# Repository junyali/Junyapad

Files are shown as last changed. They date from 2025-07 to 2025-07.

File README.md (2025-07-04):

# Junyapad

A custom 6-key macropad featuring per-key RGB LEDs (with some extras :p) a 128x32 0.91" OLD screen, a rotary encoder switch and a cool semi-open case design!

PCB designed in KiCAD, case built in OnShape, and firmware built using QMK. Pretty proud of this as it's fully independent (no assistance from friends needed or Q's asked :DD)

## Preview

| Description | Image |
|---|---|
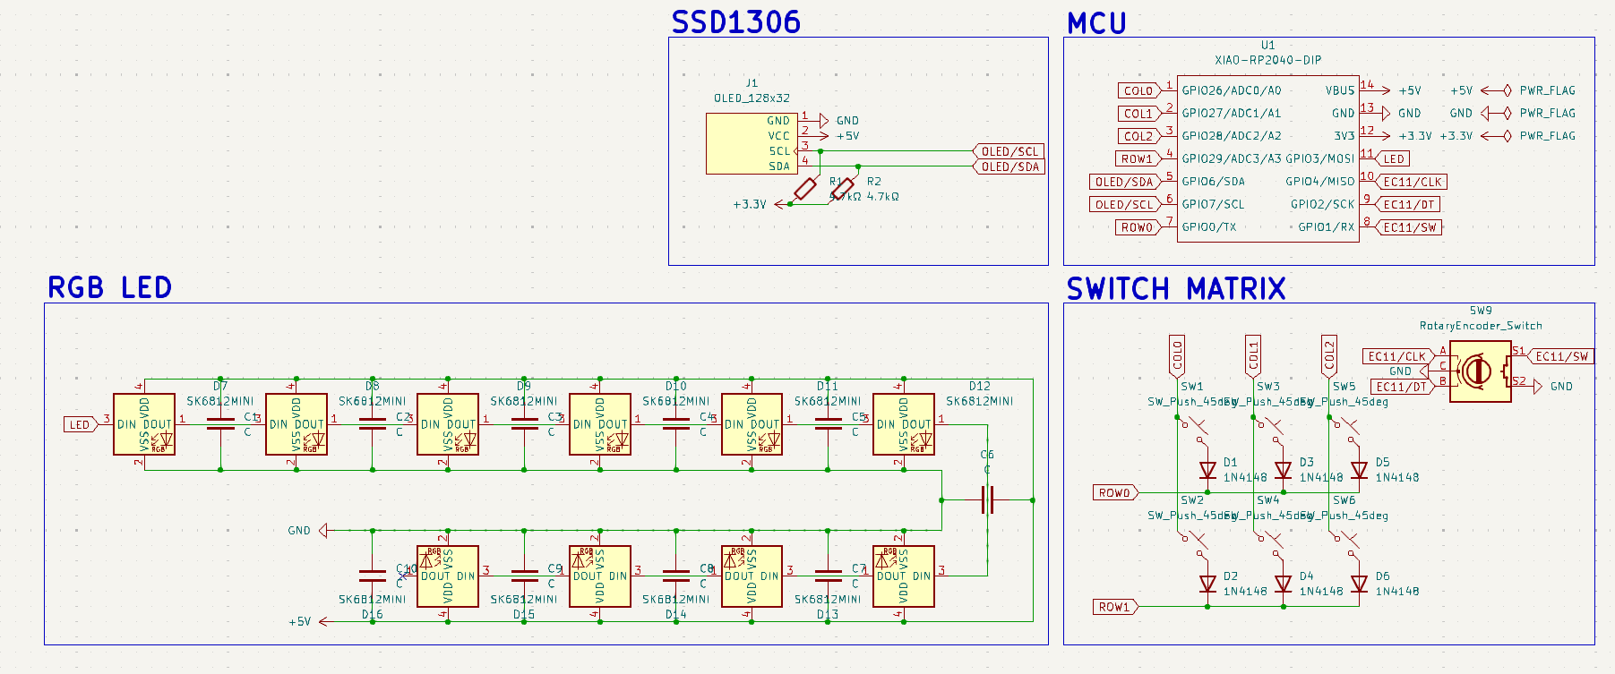
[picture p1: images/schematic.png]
| Schematic |  |
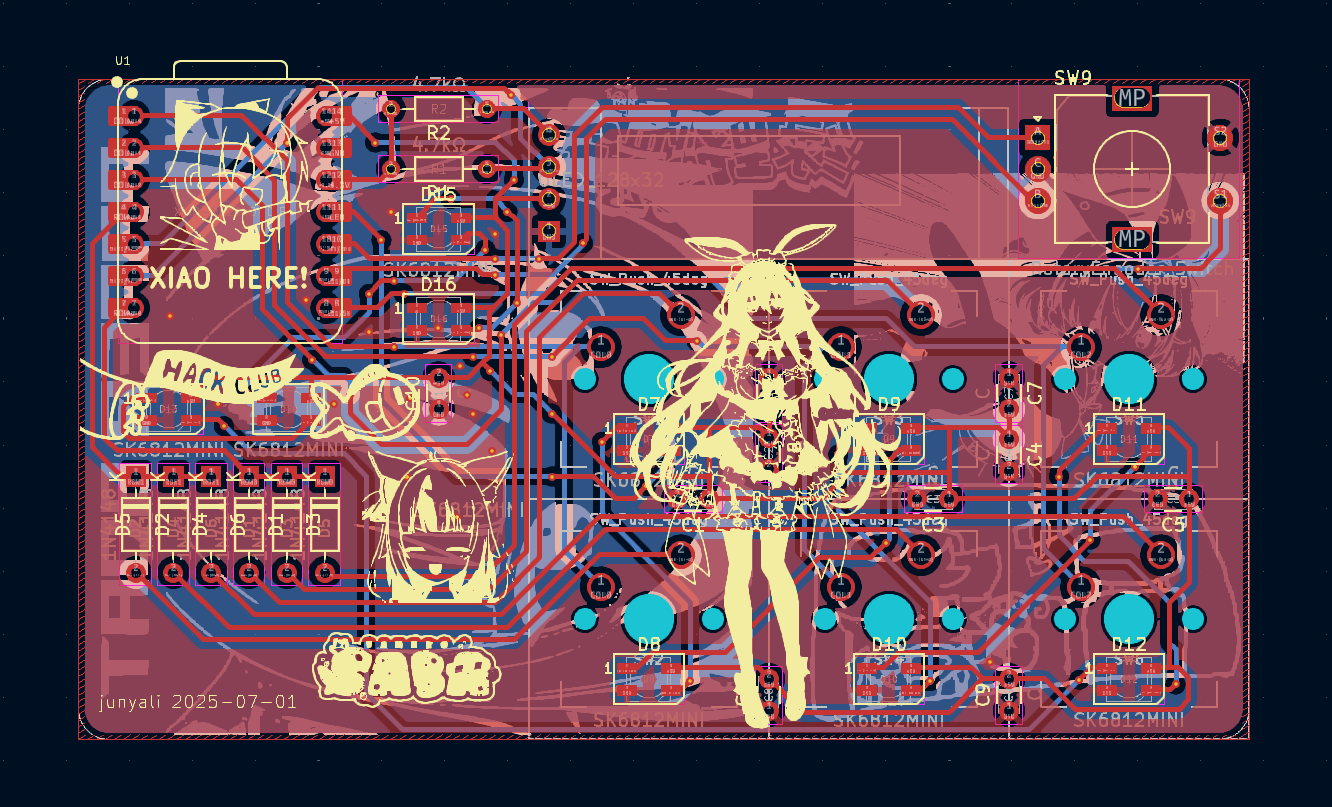
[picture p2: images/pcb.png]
| PCB |  |
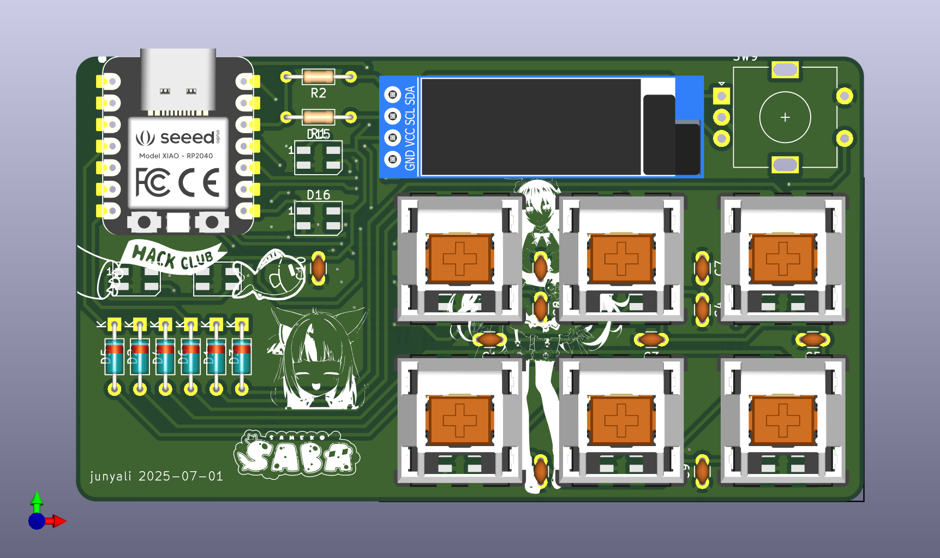
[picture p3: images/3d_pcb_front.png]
| PCB Render Front |  |
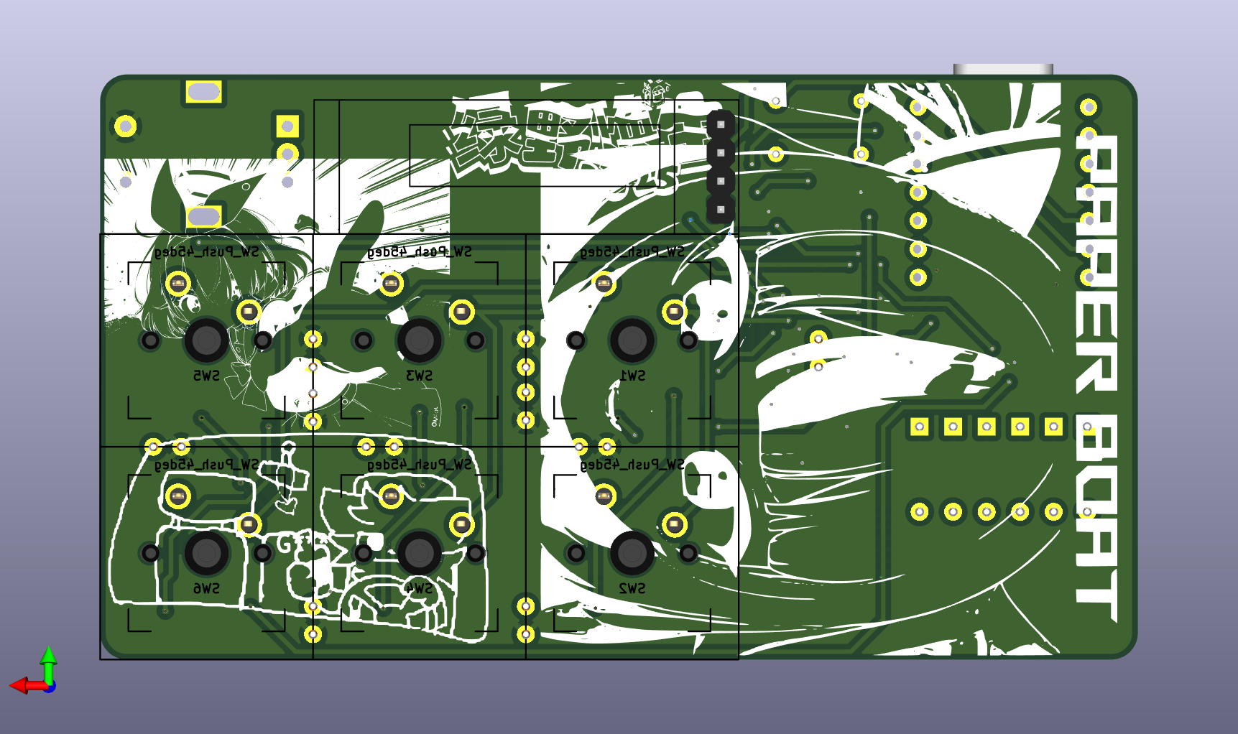
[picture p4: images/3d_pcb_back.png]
| PCB Render Back  |   |
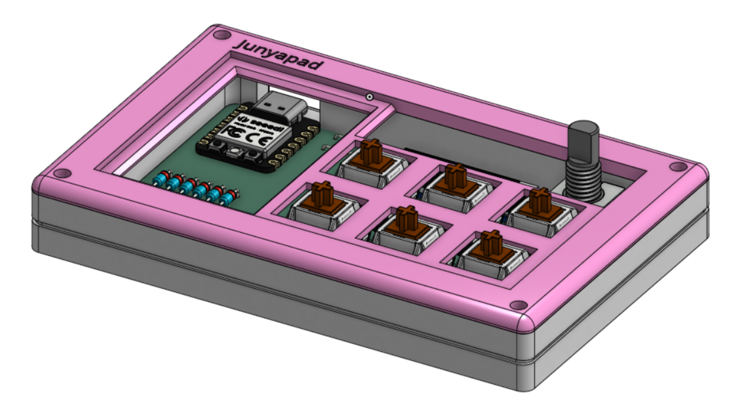
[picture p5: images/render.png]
| Case Render |  |

## BOM

| Component | Footprint | Qty | Unit Price (£) | Total Price (£) | Link |
|---|---|-----|---|---|---|
| SEEED XIAO RP2040 | XIAO-RP2040-DIP | 1 | 3.99 | 3.99 | https://www.aliexpress.com/item/1005004459618789.html |
| Cherry MX switches | N/A | 6 | 0.21 | 1.26 | https://www.aliexpress.com/item/1005006255961111.html |
| Generic Keycaps | N/A | 6 | 0.75 | 0.75 | https://www.aliexpress.com/item/1005005386897424.html |
| 1N4148 Diodes | D_DO-35_SOD27_P7.62mm_Horizontal | 6 | 0.02 | 0.12 | https://www.aliexpress.com/item/1005006245109375.html |
| SK6812 MINI LEDs | LED_SK6812MINI_PLCC4_3.5x3.5mm_P1.75mm | 10  | 0.08 | 0.80 | https://www.aliexpress.com/item/1005001971988539.html |
| 128x32 0.91" OLED Display | OLED_128x32 | 1 | 0.74 | 0.74 | https://www.aliexpress.com/item/1005008640132638.html |
| EC11 Rotary Encoder Switch | RotaryEncoder_Alps_EC11E-Switch_Vertical_H20mm | 1 | 0.74 | 0.74 | https://www.aliexpress.com/item/1005004907970664.html |
| 4.7kΩ Resistors | R_Axial_DIN0204_L3.6mm_D1.6mm_P7.62mm_Horizontal | 2 | 0.05 | 0.10 | https://www.aliexpress.com/item/1005006427040577.html |
| 0.1uF Disc Capacitors | C_Disc_D3.0mm_W1.6mm_P2.50mm | 10  | 0.01 | 0.10 | https://www.aliexpress.com/item/32973259342.html |
| M3x16mm screws | N/A | 4 | 0.04 | 0.16 | https://www.aliexpress.com/item/32844540184.html |
| M3 hex nuts | N/A | 4 | 0.03 | 0.12 | https://www.aliexpress.com/item/1005007593861199.html |
| PCB Fabricated (JLCPCB, incl shipping) | N/A | 5 | 0.94 | 4.70 | https://jlcpcb.com |
| 3D Printed Case (#printing-legion) | N/A | 1 | 0.00 | 0.00 | https://printlegion.hackclub.com |

Total Price: **£13.58** (*approx US$18.54*)

*Prices are a bit wonky since most products must be bought in bulk - this is an optimistic BOM*

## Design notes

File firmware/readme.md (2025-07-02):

# junyapad

junyapad

*A short description of the keyboard/project*

* Keyboard Maintainer: [Junya](https://github.com/junyali)
* Hardware Supported: *The PCBs, controllers supported*
* Hardware Availability: *Links to where you can find this hardware*

Make example for this keyboard (after setting up your build environment):

    make junyapad:default

Flashing example for this keyboard:

    make junyapad:default:flash

See the [build environment setup](https://docs.qmk.fm/#/getting_started_build_tools) and the [make instructions](https://docs.qmk.fm/#/getting_started_make_guide) for more information. Brand new to QMK? Start with our [Complete Newbs Guide](https://docs.qmk.fm/#/newbs).

## Bootloader

Enter the bootloader in 3 ways:

* **Bootmagic reset**: Hold down the key at (0,0) in the matrix (usually the top left key or Escape) and plug in the keyboard
* **Physical reset button**: Briefly press the button on the back of the PCB - some may have pads you must short instead
* **Keycode in layout**: Press the key mapped to `QK_BOOT` if it is available

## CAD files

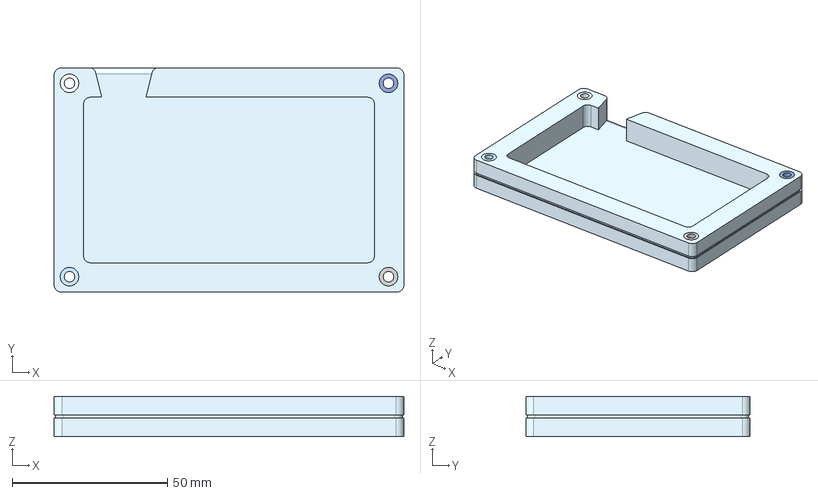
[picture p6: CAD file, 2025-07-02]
case/case_bottom.step
112.9 x 72.4 x 13.0 mm

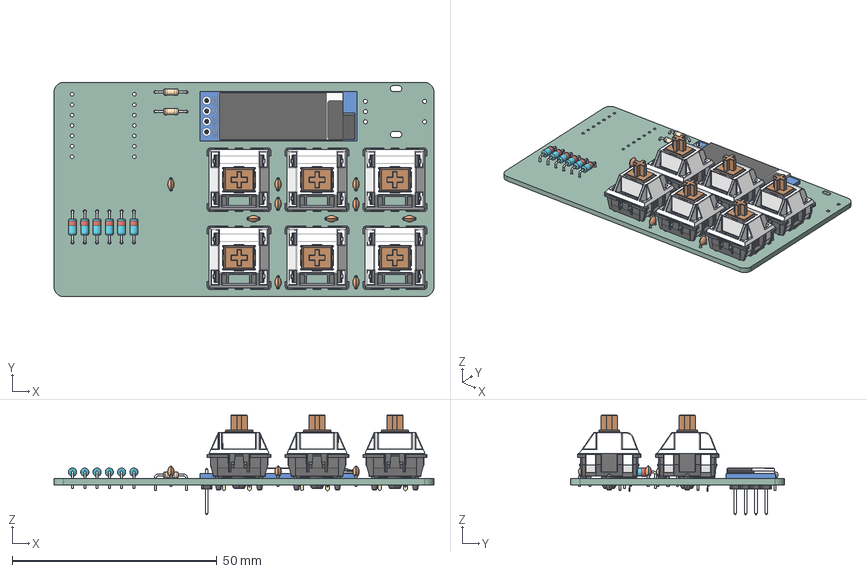
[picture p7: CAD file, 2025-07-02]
case/pcb_components.step
92.9 x 52.4 x 24.4 mm
D_DO-35_SOD27_P7.62mm_Horizontal x 6
C_Disc_D3.0mm_W1.6mm_P2.50mm x 10
R_Axial_DIN0204_L3.6mm_D1.6mm_P7.62mm_Horizontal x 2
MX_PCB x 6
OLED_0.91_128x32
Pin Header 4 x 1 TH 2.54mm Pitch
RESC-0603 x 13
2SD0601A
junyapad_PCB

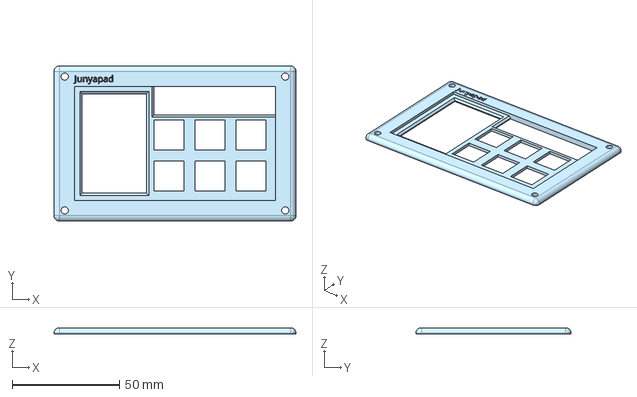
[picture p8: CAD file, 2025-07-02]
production/case/case_top.step
112.9 x 72.4 x 3.00 mm

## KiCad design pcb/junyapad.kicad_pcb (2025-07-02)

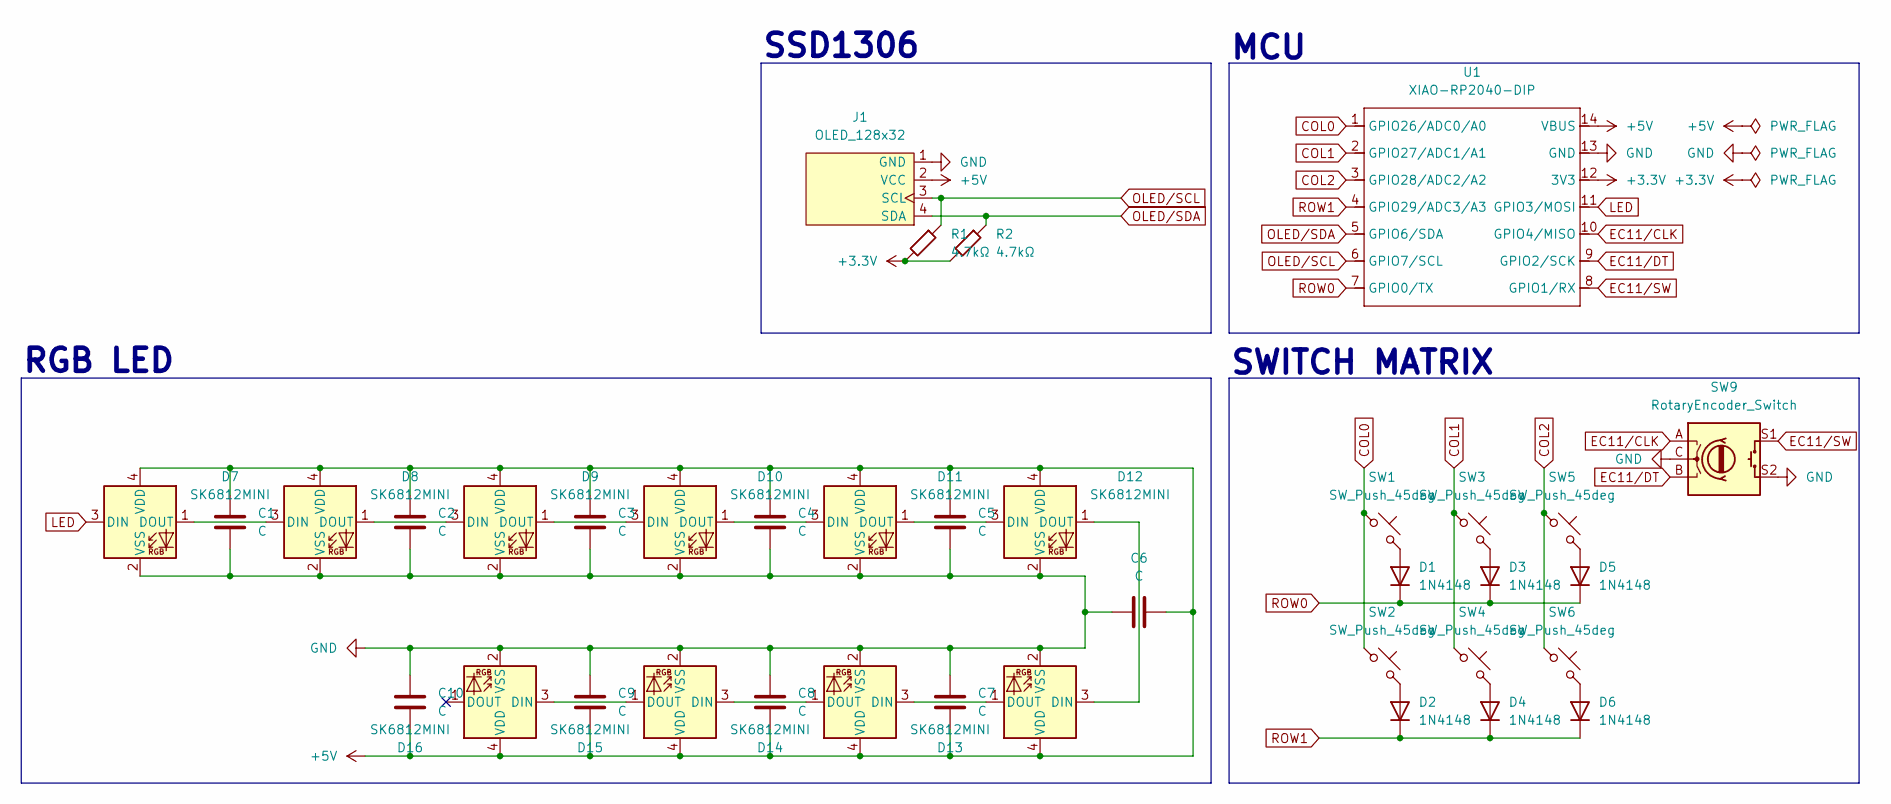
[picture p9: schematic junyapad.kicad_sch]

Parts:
C1, C2, C3, C4, C5, C6, C7, C8, C9, C10: C; C_Disc_D3.0mm_W1.6mm_P2.50mm
D1, D2, D3, D4, D5, D6: 1N4148; D_DO-35_SOD27_P7.62mm_Horizontal
D7, D8, D9, D10, D11, D12, D13, D14, D15, D16: SK6812MINI; LED_SK6812MINI_PLCC4_3.5x3.5mm_P1.75mm
J1: OLED_128x32
R1, R2: 4.7kΩ; R_Axial_DIN0204_L3.6mm_D1.6mm_P7.62mm_Horizontal
SW1, SW2, SW3, SW4, SW5, SW6: SW_Push_45deg; MX-Solderable-1U
SW9: RotaryEncoder_Switch; RotaryEncoder_Alps_EC11E-Switch_Vertical_H20mm
U1: XIAO-RP2040-DIP

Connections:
+3.3V: R1.2, R2.2, U1.12 (3V3)
+5V: C1.1, C2.1, C3.1, C4.1, C5.1, C6.2, C7.2, C8.2, C9.2, C10.2, D7.4 (VDD), D8.4 (VDD), D9.4 (VDD), D10.4 (VDD), D11.4 (VDD), D12.4 (VDD), D13.4 (VDD), D14.4 (VDD), D15.4 (VDD), D16.4 (VDD), J1.2 (VCC), U1.14 (VBUS)
COL0: SW1.1, SW2.1, U1.1 (GPIO26/ADC0/A0)
COL1: SW3.1, SW4.1, U1.2 (GPIO27/ADC1/A1)
COL2: SW5.1, SW6.1, U1.3 (GPIO28/ADC2/A2)
EC11/CLK: SW9.A, U1.10 (GPIO4/MISO)
EC11/DT: SW9.B, U1.9 (GPIO2/SCK)
EC11/SW: SW9.S1, U1.8 (GPIO1/RX)
GND: C1.2, C2.2, C3.2, C4.2, C5.2, C6.1, C7.1, C8.1, C9.1, C10.1, D7.2 (VSS), D8.2 (VSS), D9.2 (VSS), D10.2 (VSS), D11.2 (VSS), D12.2 (VSS), D13.2 (VSS), D14.2 (VSS), D15.2 (VSS), D16.2 (VSS), J1.1 (GND), SW9.C, SW9.S2, U1.13 (GND)
LED: D7.3 (DIN), U1.11 (GPIO3/MOSI)
unnamed: D1.2 (A), SW1.2
unnamed: D2.2 (A), SW2.2
unnamed: D3.2 (A), SW3.2
unnamed: D4.2 (A), SW4.2
unnamed: D5.2 (A), SW5.2
unnamed: D6.2 (A), SW6.2
unnamed: D7.1 (DOUT), D8.3 (DIN)
unnamed: D8.1 (DOUT), D9.3 (DIN)
unnamed: D9.1 (DOUT), D10.3 (DIN)
unnamed: D10.1 (DOUT), D11.3 (DIN)
unnamed: D11.1 (DOUT), D12.3 (DIN)
unnamed: D12.1 (DOUT), D13.3 (DIN)
unnamed: D13.1 (DOUT), D14.3 (DIN)
unnamed: D14.1 (DOUT), D15.3 (DIN)
unnamed: D15.1 (DOUT), D16.3 (DIN)
OLED/SCL: J1.3 (SCL), R1.1, U1.6 (GPIO7/SCL)
OLED/SDA: J1.4 (SDA), R2.1, U1.5 (GPIO6/SDA)
ROW0: D1.1 (K), D3.1 (K), D5.1 (K), U1.7 (GPIO0/TX)
ROW1: D2.1 (K), D4.1 (K), D6.1 (K), U1.4 (GPIO29/ADC3/A3)

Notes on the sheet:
SSD1306
SWITCH MATRIX
RGB LED
MCU

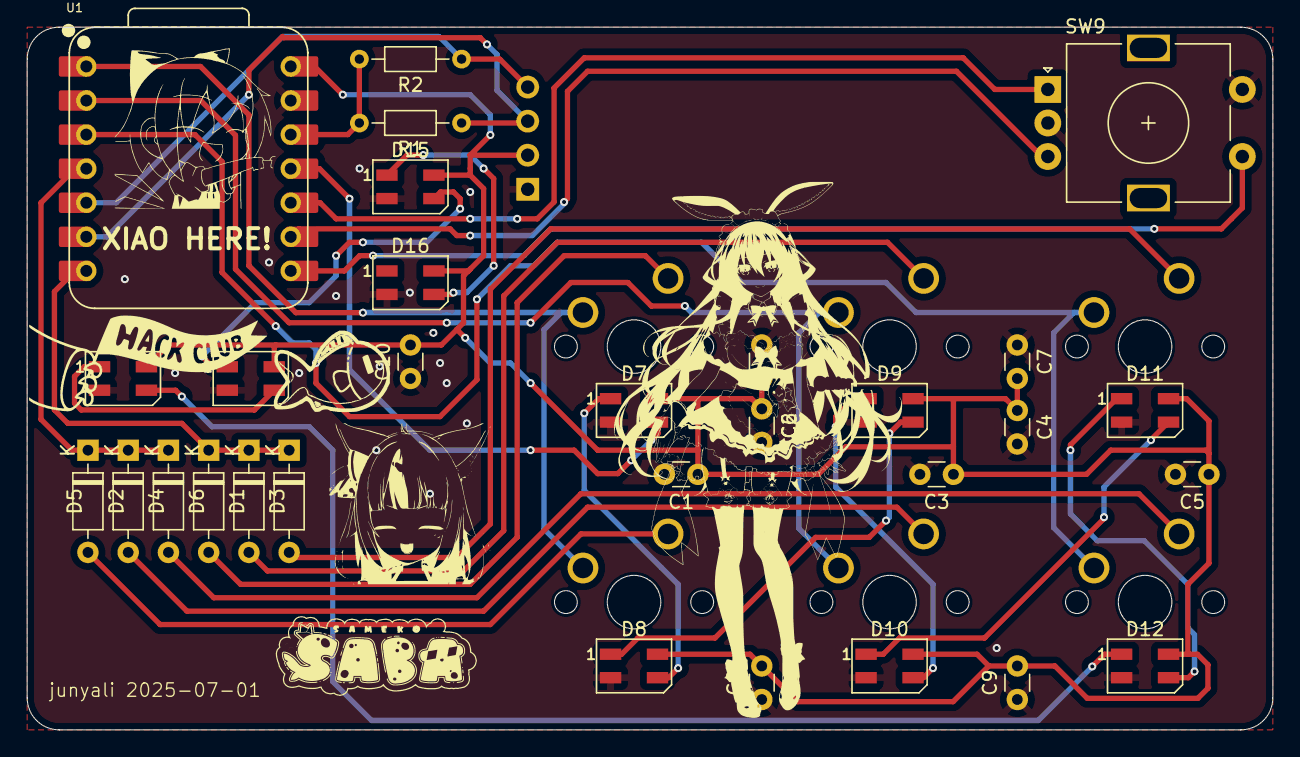
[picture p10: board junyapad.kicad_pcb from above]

Board: 2 copper layers, 92.9 x 52.4 mm, 37 parts (0 on the bottom side), 29 nets.

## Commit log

2025-07-01 Import libraries into KiCAD
2025-07-01 Setup KiCAD Project
    [junyapad.kicad_pcb, junyapad.kicad_sch]
2025-07-01 Update schematic
    [junyapad.kicad_sch]
2025-07-01 Layout PCB
    [junyapad.kicad_pcb]
2025-07-01 Rearrange Capacitors
    [junyapad.kicad_pcb]
2025-07-01 Update PCB
    [junyapad.kicad_pcb]
2025-07-02 Export CAD files
    [case_bottom.step, case_top.step, junyapad.kicad_pcb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]
2025-07-02 Generate gerbers.zip
2025-07-02 Add bom.csv
    [bom.csv]
2025-07-03 Fix BOM
    [bom.csv]
